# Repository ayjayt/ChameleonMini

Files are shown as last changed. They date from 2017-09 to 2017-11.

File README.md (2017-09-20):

Chameleon-Mini
==============
This is the official repository of ChameleonMini, a freely programmable, portable tool for NFC security analysis that can emulate and clone contactless cards, read RFID tags and sniff/log RF data. Thanks to over 1700 backers from our [Kickstarter project](https://www.kickstarter.com/projects/1980078555/chameleonmini-a-versatile-nfc-card-emulator-and-mo), the current Revision G has been realized by Kasper & Oswald GmbH.

The ChameleonMini RevG is now also available via the Kasper & Oswald [Webshop](https://shop.kasper.it/). Thank you for supporting the project!

First Steps
-----------
To upgrade the firmware of your ChameleonMini, please visit the [Getting Started page](http://rawgit.com/emsec/ChameleonMini/master/Doc/Doxygen/html/Page_GettingStarted.html) from the [doxygen documentation](http://rawgit.com/emsec/ChameleonMini/master/Doc/Doxygen/html/index.html).

Supported Cards and Codecs
--------------------------
See [here](https://github.com/emsec/ChameleonMini/wiki/Supported-Cards-and--Codecs).

Questions
---------
If you have any questions, please visit the [Issues page](https://github.com/emsec/ChameleonMini/issues) and ask your questions there so everyone benefits from the answer.

Repository Structure
--------------------
The code repository contains
* Doc: A doxygen documentation 
* Drivers: Chameleon drivers for Windows and Linux
* Dumps: Dumps of different smartcards
* Hardware: The layout and schematics of the PCB
* Firmware: The complete firmware including a modified Atmel DFU bootloader and LUFA
* Software: Contains a python tool for an easy configuration (and more) of the ChameleonMini, Note that this is currently under construction
* RevE: Contains the whole contents of the discontinued RevE repository.

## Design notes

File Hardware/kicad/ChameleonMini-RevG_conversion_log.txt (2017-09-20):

#********** START OF renumber-sheet.ulp ULP Version 4.4.4 08-08-2017 :04:16:28 LOG **********#
#OldRef				SheetNumber	NewRef
B+				1	B+53
B-				1	B-53
LBUTTON				1	LBUTTON53
LEDGREEN				1	LEDGREEN53
LEDRED				1	LEDRED53
RBTN				1	RBTN53
#********** END OF renumber-sheet.ulp ULP Version 4.4.4 08-08-2017 :04:16:28 LOG **********#

#********** START OF fix_via_hack.ulp ULP Version 4.7.0 08-08-2017 :04:16:36 LOG **********#
TRACK	WireCount=1		Net=+3V3				start(X=34925.000000 Y=49212.500000)	end(X=34925.000000 Y=51435.000000 )
TRACK	WireCount=2		Net=N$22				start(X=48463.200000 Y=59436.000000)	end(X=48463.200000 Y=59131.200000 )
TRACK	WireCount=3		Net=N$22				start(X=48463.200000 Y=59131.200000)	end(X=48158.400000 Y=59131.200000 )
TRACK	WireCount=4		Net=N$22				start(X=48158.400000 Y=59131.200000)	end(X=48158.400000 Y=59436.000000 )
TRACK	WireCount=5		Net=N$22				start(X=48158.400000 Y=59131.200000)	end(X=48158.400000 Y=58826.400000 )
TRACK	WireCount=6		Net=N$23				start(X=47853.600000 Y=59436.000000)	end(X=47548.800000 Y=59436.000000 )
TRACK	WireCount=7		Net=N$23				start(X=47548.800000 Y=59436.000000)	end(X=47548.800000 Y=59131.200000 )
TRACK	WireCount=8		Net=N$23				start(X=47548.800000 Y=59131.200000)	end(X=47853.600000 Y=59131.200000 )
TRACK	WireCount=9		Net=N$23				start(X=47853.600000 Y=59131.200000)	end(X=47853.600000 Y=58826.400000 )
TRACK	WireCount=10		Net=N$23				start(X=47853.600000 Y=58826.400000)	end(X=47548.800000 Y=58826.400000 )
VIA	ViaCount=1		Net=+3V3				(X=34925.000000 Y=49212.500000)	LayerStart=1	LayerEnd=16
VIA	ViaCount=2		Net=+3V3				(X=34925.000000 Y=51435.000000)	LayerStart=1	LayerEnd=16
VIA	ViaCount=3		Net=GND				(X=36512.400000 Y=63341.200000)	LayerStart=1	LayerEnd=16
VIA	ViaCount=4		Net=GND				(X=45720.000000 Y=24447.500000)	LayerStart=1	LayerEnd=16
PADFILL	PadCount=2		Net=GND				(X=42227.500000 Y=70485.000000)	LayerStart=16	LayerEnd=16
PADFILL	PadCount=5		Net=GND				(X=39052.500000 Y=36195.000000)	LayerStart=16	LayerEnd=16
PADFILL	PadCount=22		Net=+3V3				(X=47702.500000 Y=61912.500000)	LayerStart=1	LayerEnd=1
PADFILL	PadCount=24		Net=+3V3				(X=44132.600000 Y=36435.000000)	LayerStart=1	LayerEnd=1
PADFILL	PadCount=28		Net=+3V3				(X=33178.800000 Y=32942.500000)	LayerStart=1	LayerEnd=1
PADFILL	PadCount=30		Net=+3V3				(X=35320.000000 Y=59372.500000)	LayerStart=1	LayerEnd=1
PADFILL	PadCount=32		Net=+3V3				(X=40322.500000 Y=41987.500000)	LayerStart=1	LayerEnd=1
PADFILL	PadCount=34		Net=+3V3				(X=46277.500000 Y=63500.000000)	LayerStart=1	LayerEnd=1
PADFILL	PadCount=40		Net=+3V3				(X=46990.000000 Y=53897.500000)	LayerStart=1	LayerEnd=1
PADFILL	PadCount=42		Net=+3V3				(X=27700.000000 Y=53975.000000)	LayerStart=1	LayerEnd=1
PADFILL	PadCount=64		Net=+3V3				(X=40163.700000 Y=32942.500000)	LayerStart=1	LayerEnd=1
PADFILL	PadCount=68		Net=+3V3				(X=49212.400000 Y=39292.500000)	LayerStart=1	LayerEnd=1
PADFILL	PadCount=94		Net=+3V3				(X=40500.000000 Y=45952.500000)	LayerStart=1	LayerEnd=1
PADFILL	PadCount=104		Net=+3V3				(X=43900.000000 Y=53352.500000)	LayerStart=1	LayerEnd=1
PADFILL	PadCount=116		Net=+3V3				(X=35700.000000 Y=57552.500000)	LayerStart=1	LayerEnd=1
PADFILL	PadCount=124		Net=+3V3				(X=32300.000000 Y=51752.500000)	LayerStart=1	LayerEnd=1
PADFILL	PadCount=131		Net=+3V3				(X=47795.000000 Y=63502.500000)	LayerStart=1	LayerEnd=1
PADFILL	PadCount=137		Net=+3V3				(X=47005.000000 Y=35662.500000)	LayerStart=1	LayerEnd=1
PADFILL	PadCount=142		Net=+3V3				(X=46252.500000 Y=40337.500000)	LayerStart=1	LayerEnd=1
PADFILL	PadCount=145		Net=+3V3				(X=44072.500000 Y=58102.500000)	LayerStart=1	LayerEnd=1
PADFILL	PadCount=149		Net=+3V3				(X=49272.500000 Y=59372.500000)	LayerStart=1	LayerEnd=1
PADFILL	PadCount=150		Net=+3V3				(X=49272.500000 Y=60642.500000)	LayerStart=1	LayerEnd=1
PADFILL	PadCount=156		Net=+3V3				(X=42477.500000 Y=37110.000000)	LayerStart=1	LayerEnd=1
PADFILL	PadCount=157		Net=+3V3				(X=41977.500000 Y=37110.000000)	LayerStart=1	LayerEnd=1
PADFILL	PadCount=158		Net=+3V3				(X=41477.500000 Y=37110.000000)	LayerStart=1	LayerEnd=1
PADFILL	PadCount=163		Net=+3V3				(X=34940.000000 Y=35345.000000)	LayerStart=1	LayerEnd=1
PADFILL	PadCount=168		Net=+3V3				(X=38750.000000 Y=35345.000000)	LayerStart=1	LayerEnd=1
PADFILL	PadCount=214		Net=+3V3				(X=38900.000000 Y=33987.500000)	LayerStart=1	LayerEnd=1
PADFILL	PadCount=217		Net=+3V3				(X=34442.500000 Y=32687.500000)	LayerStart=1	LayerEnd=1
PADFILL	PadCount=226		Net=+3V3				(X=35457.500000 Y=60642.500000)	LayerStart=1	LayerEnd=1
PADFILL	PadCount=239		Net=+3V3				(X=40005.000000 Y=36297.500000)	LayerStart=1	LayerEnd=1
PADFILL	PadCount=246		Net=+3V3				(X=43395.000000 Y=31115.100000)	LayerStart=1	LayerEnd=1
PADFILL	PadCount=247		Net=+3V3				(X=46252.500000 Y=61912.500000)	LayerStart=1	LayerEnd=1
PADFILL	PadCount=256		Net=+3V3				(X=36195.000000 Y=36297.500000)	LayerStart=1	LayerEnd=1
PADFILL	PadCount=272		Net=+3V3				(X=48792.500000 Y=55403.700000)	LayerStart=1	LayerEnd=1
PADFILL	PadCount=298		Net=+3V3				(X=28035.000000 Y=52070.000000)	LayerStart=1	LayerEnd=1
#********** END OF fix_via_hack.ulp ULP Version 4.7.0 08-08-2017 :04:16:36 LOG **********#

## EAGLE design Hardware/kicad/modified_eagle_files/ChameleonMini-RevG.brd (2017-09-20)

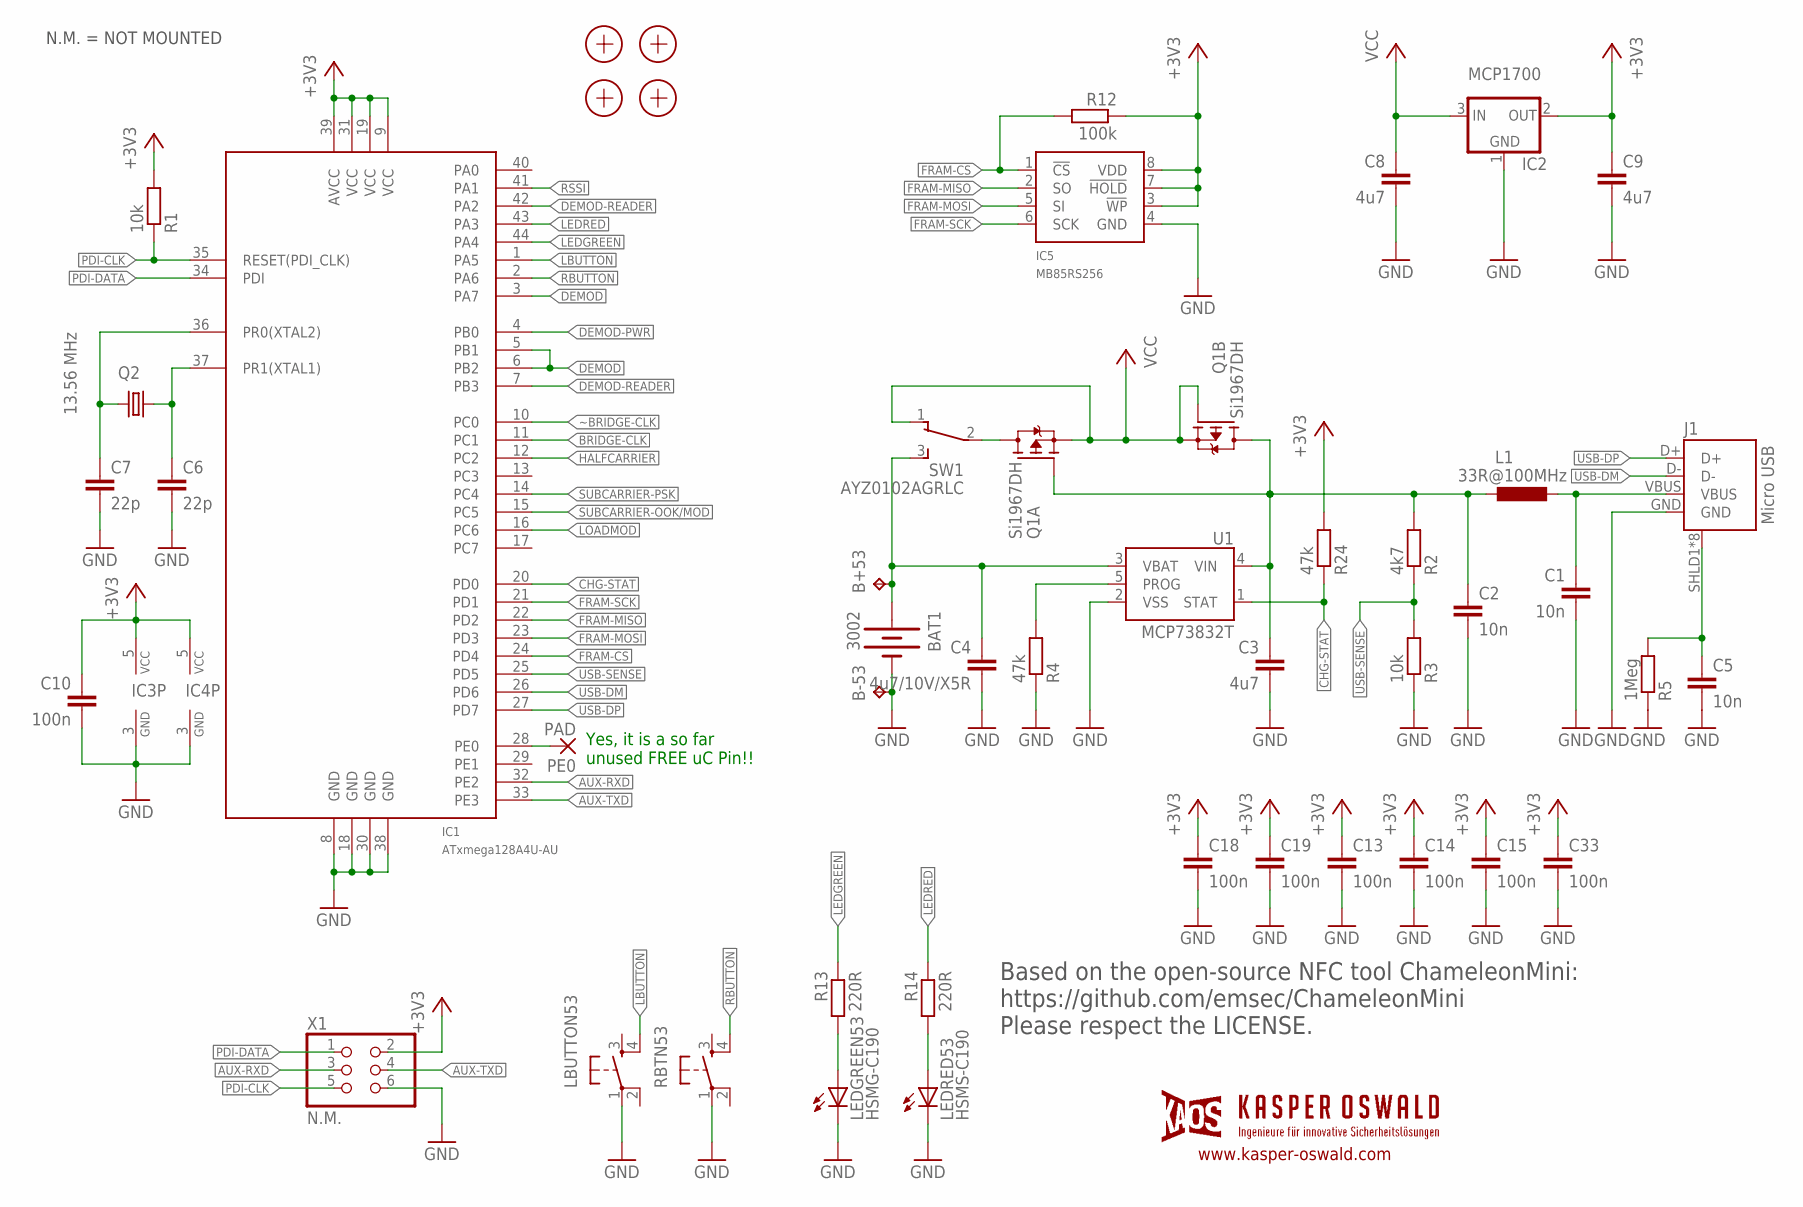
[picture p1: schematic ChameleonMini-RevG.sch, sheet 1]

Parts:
B+53: TPTP18SQ; TP18SQ
B-53: TPTP18SQ; TP18SQ
BAT1: 3002; BATTCON_20MM
C1, C2: 10n; C1206K
C3, C8, C9: 4u7; C0603K
C4: 4u7/10V/X5R; C0603K
C5: 10n; C0603K
C6, C7: 22p; C0603K
C10, C13, C14, C15, C18, C19, C33: 100n; C0603K
IC1: ATxmega128A4U-AU; TQFP44
IC2: MCP1700; SOT23
IC3: 7408; SC70-5
IC4: 7486; SC70-5
IC5: MB85RS256; SO-08
J1: Micro USB; USB-MICROB-10118194
L1: 33R@100MHz; L2012C
LBUTTON53: SWITCH_SPST_4_PINSQUARE; TACTILE-SWITCH-SMD
LEDGREEN53: HSMG-C190; CHIPLED-0603
LEDRED53: HSMS-C190; CHIPLED-0603
PE0: PAD; SMD1,27-2,54
Q1: Si1967DH; SOT363
Q2: 13.56 MHz; 5MMX3.2MM
R1, R3: 10k; R0603
R2: 4k7; R0603
R4, R24: 47k; R0603
R5: 1Meg; R0603
R12: 100k; R0603
R13, R14: 220R; R0603
RBTN53: SWITCH_SPST_4_PINSQUARE; TACTILE-SWITCH-SMD
SW1: AYZ0102AGRLC
U1: MCP73832T; SOT23-5
X1: N.M.; PINHD-2X3-2.54-EDGE
X2, X4, X5, X6: PASSER-07; PASSER_07MM

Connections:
+3V3: C9.1, C10.1, C13.1, C14.1, C15.1, C18.1, C19.1, C33.1, IC1.9 (VCC), IC1.19 (VCC), IC1.31 (VCC), IC1.39 (AVCC), IC2.2 (OUT), IC3.5 (VCC), IC4.5 (VCC), IC5.3 (!WP), IC5.7 (!HOLD), IC5.8 (VDD), R1.2, R12.1, R24.2, X1.2; also elsewhere on the board
AUX-RXD: IC1.32 (PE2), X1.3
AUX-TXD: IC1.33 (PE3), X1.4
BRIDGE-CLK: IC1.11 (PC1); also elsewhere on the board
CHG-STAT: IC1.20 (PD0), R24.1, U1.1 (STAT)
DEMOD: IC1.3 (PA7), IC1.5 (PB1), IC1.6 (PB2); also elsewhere on the board
DEMOD-PWR: IC1.4 (PB0); also elsewhere on the board
DEMOD-READER: IC1.7 (PB3), IC1.42 (PA2); also elsewhere on the board
FRAM-CS: IC1.24 (PD4), IC5.1 (!CS), R12.2
FRAM-MISO: IC1.22 (PD2), IC5.2 (SO)
FRAM-MOSI: IC1.23 (PD3), IC5.5 (SI)
FRAM-SCK: IC1.21 (PD1), IC5.6 (SCK)
GND: B-53.TP, BAT1.-, C1.2, C2.2, C3.2, C4.2, C5.2, C6.2, C7.2, C8.2, C9.2, C10.2, C13.2, C14.2, C15.2, C18.2, C19.2, C33.2, IC1.8 (GND), IC1.18 (GND), IC1.30 (GND), IC1.38 (GND), IC2.1 (GND), IC3.3 (GND), IC4.3 (GND), IC5.4 (GND), J1.GND, LBUTTON53.1, LEDGREEN53.C, LEDRED53.C, R3.1, R4.1, R5.1, RBTN53.1, U1.2 (VSS), X1.6; also elsewhere on the board
HALFCARRIER: IC1.12 (PC2); also elsewhere on the board
LBUTTON: IC1.1 (PA5), LBUTTON53.4
LEDGREEN: IC1.44 (PA4), R13.1
LEDRED: IC1.43 (PA3), R14.1
LOADMOD: IC1.16 (PC6); also elsewhere on the board
unnamed: C7.1, IC1.36 (PR0(XTAL2)), Q2.3 (2)
unnamed: C1.1, J1.VBUS, L1.1
unnamed: C6.1, IC1.37 (PR1(XTAL1)), Q2.1
unnamed: LEDGREEN53.A, R13.2
unnamed: LEDRED53.A, R14.2
unnamed: Q1.6 (D), SW1.2
unnamed: C2.1, C3.1, L1.2, Q1.2 (G), Q1.3 (D), R2.2, U1.4 (VIN)
unnamed: IC1.28 (PE0), PE0.1
unnamed: R4.2, U1.5 (PROG)
unnamed: B+53.TP, BAT1.+2 (+), C4.1, SW1.3 (S), U1.3 (VBAT)
unnamed: C5.1, J1.SHLD1 (SHIELD), J1.SHLD2 (SHIELD), J1.SHLD3 (SHIELD), J1.SHLD4 (SHIELD), J1.SHLD5 (SHIELD), J1.SHLD6 (SHIELD), J1.SHLD7 (SHIELD), J1.SHLD8 (SHIELD), R5.2
PDI-CLK: IC1.35 (RESET(PDI_CLK)), R1.1, X1.5
PDI-DATA: IC1.34 (PDI), X1.1
RBUTTON: IC1.2 (PA6), RBTN53.4
RSSI: IC1.41 (PA1); also elsewhere on the board
SUBCARRIER-OOK/MOD: IC1.15 (PC5); also elsewhere on the board
SUBCARRIER-PSK: IC1.14 (PC4); also elsewhere on the board
USB-DM: IC1.26 (PD6), J1.D-
USB-DP: IC1.27 (PD7), J1.D+
USB-SENSE: IC1.25 (PD5), R2.1, R3.2
VCC: C8.1, IC2.3 (IN), Q1.1 (S), Q1.4 (S), Q1.5 (G), SW1.1 (O)
~BRIDGE-CLK: IC1.10 (PC0); also elsewhere on the board

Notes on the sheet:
Based on the open-source NFC tool ChameleonMini: https://github.com/emsec/ChameleonMini Please respect the LICENSE.
N.M. = NOT MOUNTED
Yes, it is a so far unused FREE uC Pin!!
www.kasper-oswald.com

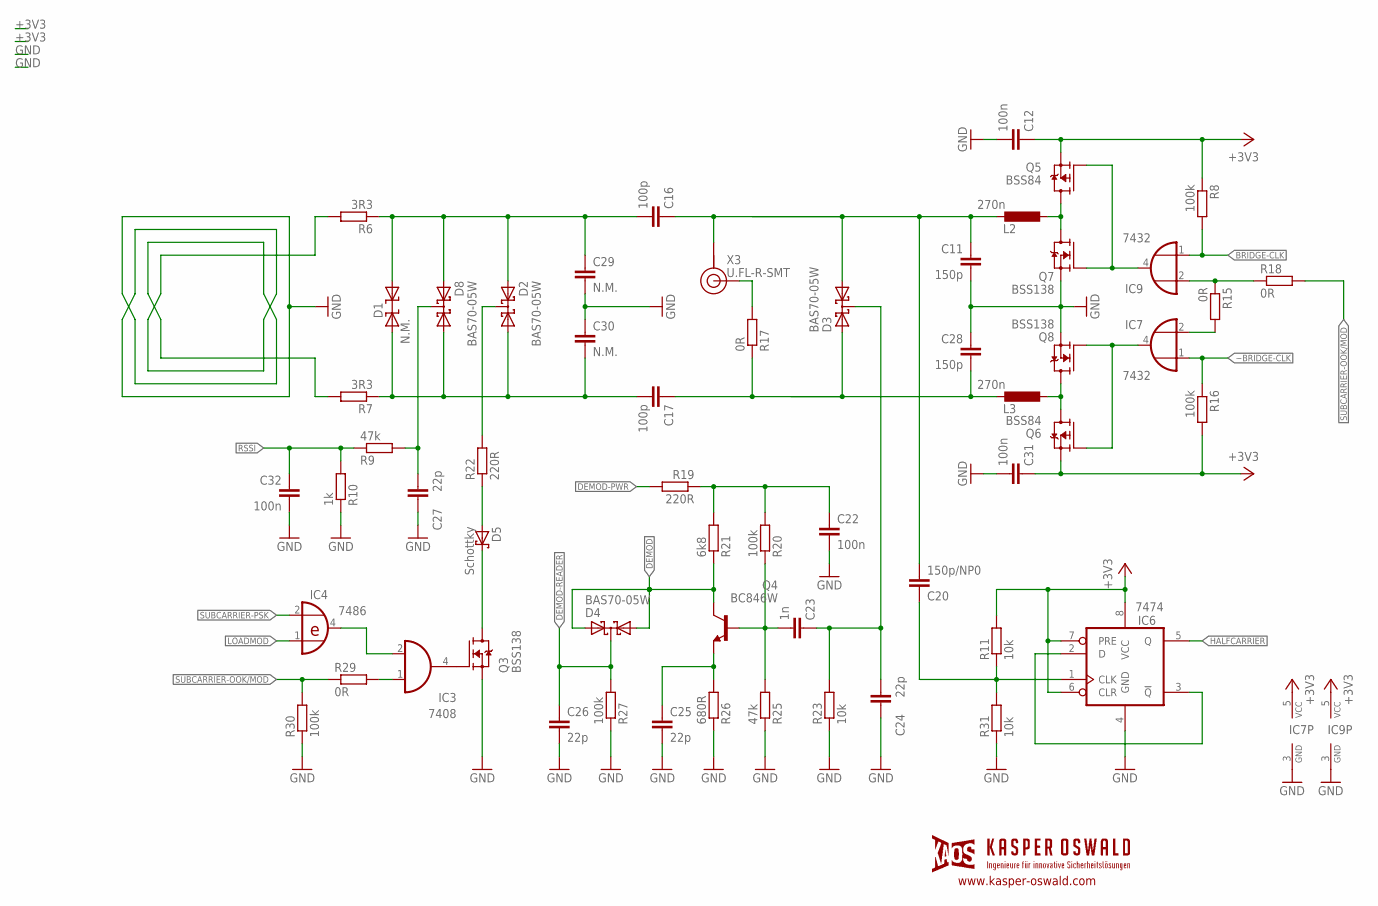
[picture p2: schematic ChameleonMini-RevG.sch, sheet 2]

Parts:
C11, C28: 150p; C0603K
C12, C22, C31, C32: 100n; C0603K
C16, C17: 100p; C0603K
C20: 150p/NP0; C0603K
C23: 1n; C0603K
C24, C25, C26, C27: 22p; C0603K
C29, C30: N.M.; C0603K
D1: N.M.; DO214AC
D2, D3, D4, D8: BAS70-05W; SOT323
D5: Schottky; SOD323(F)
IC3: 7408; SC70-5
IC4: 7486; SC70-5
IC6: 7474; VSSOP8
IC7, IC9: 7432; SC70-5
L2, L3: 270n; L2012C
Q3, Q7, Q8: BSS138; SOT323
Q4: BC846W; SOT323
Q5, Q6: BSS84; SOT323
R6, R7: 3R3; R0603
R8, R16, R20, R27, R30: 100k; R0603
R9, R25: 47k; R0603
R10: 1k; R0603
R11, R23, R31: 10k; R0603
R15, R17, R18, R29: 0R; R0603
R19, R22: 220R; R0603
R21: 6k8; R0603
R26: 680R; R0603
X3: U.FL-R-SMT

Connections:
+3V3: C12.1, C31.1, IC6.6 (CLR), IC6.7 (PRE), IC6.8 (VCC), IC7.5 (VCC), IC9.5 (VCC), Q5.2 (S), Q6.2 (S), R8.1, R11.2, R16.2; also elsewhere on the board
ANTENNA-A: C11.1, C16.1, C20.2, D3.2 (A2), L2.2, X3.GND1 (GND)
ANTENNA-B: C17.1, C28.2, D3.1 (A1), L3.2, R17.1
BRIDGE-1: IC9.4 (O), Q5.1 (G), Q7.1 (G)
BRIDGE-2: IC7.4 (O), Q6.1 (G), Q8.1 (G)
BRIDGE-CLK: IC9.1 (I0), R8.2; also elsewhere on the board
DEMOD: D4.1 (A1), D4.2 (A2), Q4.3 (C), R21.1; also elsewhere on the board
DEMOD-PWR: R19.2; also elsewhere on the board
DEMOD-READER: C26.1, D4.3 (K), R27.2; also elsewhere on the board
GND: C11.2, C12.2, C22.2, C24.2, C25.2, C26.2, C27.2, C28.1, C29.2, C30.1, C31.2, C32.2, IC6.4 (GND), IC7.3 (GND), IC9.3 (GND), Q3.2 (S), Q7.2 (S), Q8.2 (S), R6.2, R7.2, R10.1, R23.1, R25.1, R26.1, R27.1, R30.1, R31.1; also elsewhere on the board
HALFCARRIER: IC6.5 (Q); also elsewhere on the board
LOADMOD: IC4.1 (I0); also elsewhere on the board
MOD-DEMOD: D2.3 (K), R22.2
MOD-DEMOD1: C23.1, C24.1, D3.3 (K), R23.2
unnamed: C25.1, Q4.2 (E), R26.2
unnamed: IC7.2 (I1), R15.2
unnamed: D5.1 (K), Q3.3 (D)
unnamed: IC6.2 (D), IC6.3 (!Q)
unnamed: C16.2, C29.1, D1.2, D2.1 (A1), D8.1 (A1), R6.1
unnamed: L2.1, Q5.3 (D), Q7.3 (D)
unnamed: IC3.2 (I1), IC4.4 (O)
unnamed: D5.2 (A), R22.1
unnamed: IC3.4 (O), Q3.1 (G)
unnamed: R17.2, X3.SIG
unnamed: L3.1, Q6.3 (D), Q8.3 (D)
unnamed: C17.2, C30.2, D1.1, D2.2 (A2), D8.2 (A2), R7.1
unnamed: C27.1, D8.3 (K), R9.2
unnamed: IC9.2 (I1), R15.1, R18.1
unnamed: C23.2, Q4.1 (B), R20.1, R25.2
unnamed: C20.1, IC6.1 (CLK), R11.1, R31.2
unnamed: IC3.1 (I0), R29.2
unnamed: C22.1, R19.1, R20.2, R21.2
RSSI: C32.1, R9.1, R10.2; also elsewhere on the board
SUBCARRIER-OOK/MOD: R18.2, R29.1, R30.2; also elsewhere on the board
SUBCARRIER-PSK: IC4.2 (I1); also elsewhere on the board
~BRIDGE-CLK: IC7.1 (I0), R16.1; also elsewhere on the board

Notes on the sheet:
www.kasper-oswald.com

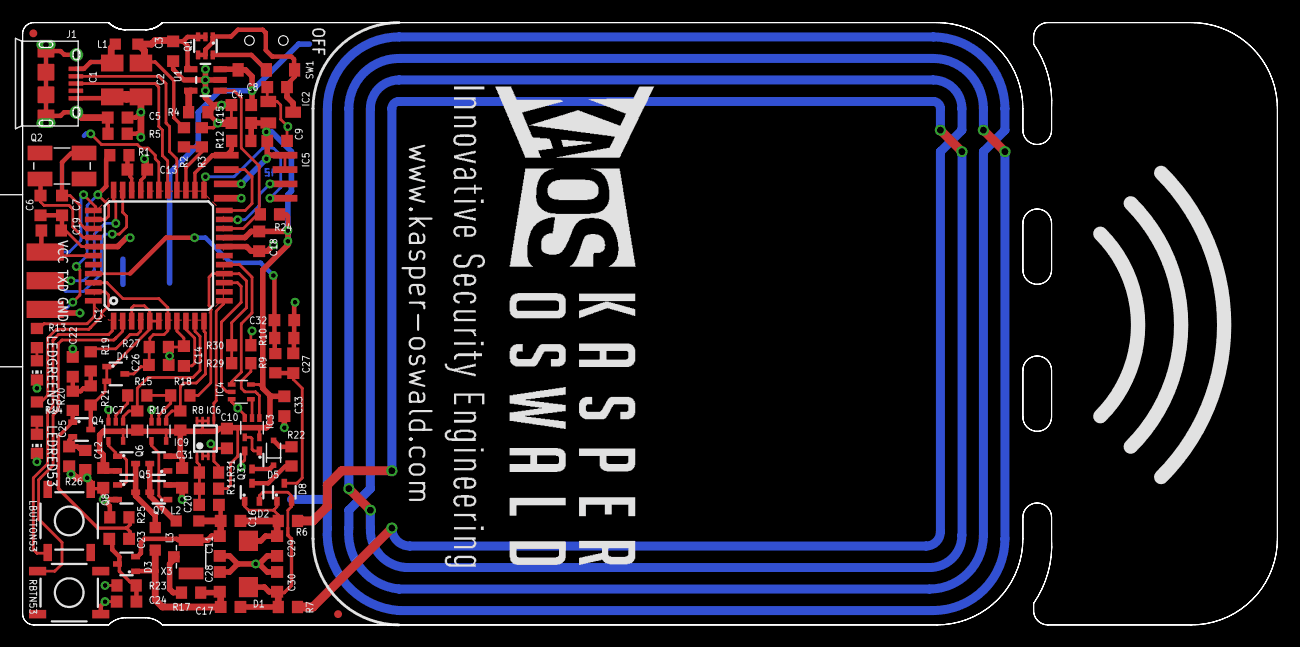
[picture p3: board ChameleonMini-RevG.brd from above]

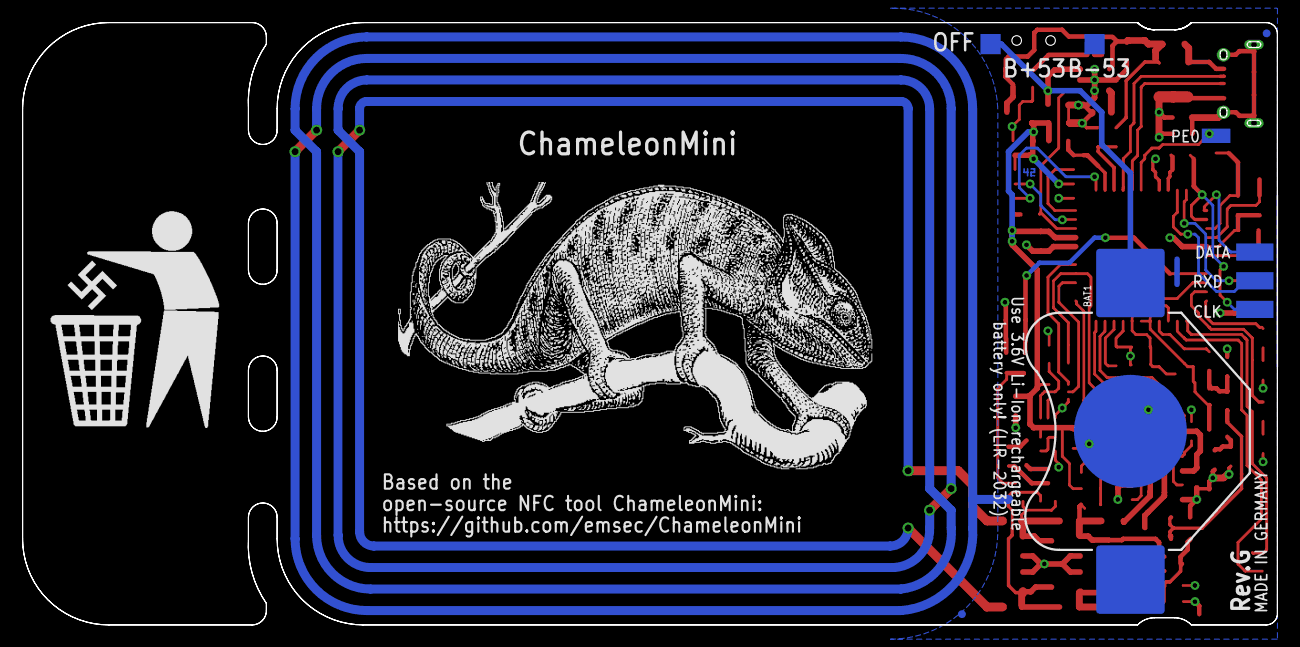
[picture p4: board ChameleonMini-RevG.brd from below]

Board: 2 copper layers, 111.1 x 53.3 mm, 104 parts (6 on the bottom side), 64 nets.

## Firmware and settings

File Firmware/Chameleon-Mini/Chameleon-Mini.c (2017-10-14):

#include "Chameleon-Mini.h"
#include <avr/sleep.h>
#include <avr/io.h>
#include <avr/power.h>

void enableUSARTD1(void){
		PORTD.OUT |= PIN7_bm;
		PORTD.DIRSET = PIN7_bm;
		PORTD.DIRCLR = PIN6_bm;
		USARTD1.CTRLC = (uint8_t) USART_CHSIZE_8BIT_gc | (0b11<<4);
    USARTD1.BAUDCTRLA = (uint8_t) (3270);
    USARTD1.BAUDCTRLB = ( 0b1001 << USART_BSCALE0_bp ) | ( 3270>>8 );
		
	  USARTD1.CTRLB |= USART_RXEN_bm;
		USARTD1.CTRLB |= USART_TXEN_bm;
}


int main(void)
{
	SystemInit(); // watchdog and oscillator stuff
	SettingsLoad(); // loads stuff from ee
	LEDInit(); // Sets direction Register
	MemoryInit(); //FRAM DMA stuff 
	CodecInitCommon(); // Does Pins for Modems
	ConfigurationInit(); // loads new configuration and finishes CodecInit
	enableUSARTD1();
	TerminalInit(); // sets port direction pon pind5 // senses usb, might be why clock turns back on
	RandomInit(); // empty function (literally 0 lines)
	ButtonInit(); // just some pullups and stuff
	AntennaLevelInit(); // sets ome things
	LogInit();
	SystemInterruptInit(); // Just enable all interrupts

	CLK.USBCTRL &= ~(1);
	USB.CTRLA &= ~(1<<7);
	SystemStopUSBClock();
	
	

	while(1) {
		
		if (SystemTick100ms()) {
			RandomTick(); // "entropy generator"
			TerminalTick(); // PRETTY INVOLVED, ./Termina/* needs going through
			ButtonTick(); //Any results are stored in the settings structure (including button action function)
			LogTick(); //
			LEDTick(); //

			ApplicationTick(); // believe this is mifare related, CHECK
			CommandLineTick();  // happens in TerminalTick too, doesn't look like it does much
			AntennaLevelTick(); //
		}
		TerminalTask();
		LogTask();
		ApplicationTask();
		CodecTask();
		newUART();
	}
}

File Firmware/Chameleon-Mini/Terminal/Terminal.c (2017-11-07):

#include "Terminal.h"
#include "../System.h"
#include "../LEDHook.h"

// ptc is a layer to handle uart output
void ptc(char c){
	do{
			/* Wait until it is possible to put data into TX data register.*/
	} while(!( (USARTD1.STATUS & USART_DREIF_bm) != 0));
	USARTD1.DATA = c;
}
// pts is a loop of pts
void pts(const char * str, uint16_t len){
	uint8_t i = 0;
	if (len){
		for(; i < len; i++){
			ptc(str[i]);
		}
	} else {
		while (str[i] != 0){
			ptc(str[i++]);
		} ptc(0);
	}
}
// ftc is a layer to handle uart input
volatile int16_t gtc(){
	volatile int16_t recv;
	if (USARTD1.STATUS & USART_RXCIF_bm) {
		recv = USARTD1.DATA;
		//ptc((char)recv); // get rid of this get rid of this get rid of this
		return (int16_t) recv;
	} else {
		return -1;
	}
}

#define INIT_DELAY		(2000 / SYSTEM_TICK_MS)


uint8_t TerminalBuffer[TERMINAL_BUFFER_SIZE];
TerminalStateEnum TerminalState = TERMINAL_UNINITIALIZED;

// TerminalSendString was part of Terminmal.c for USB so I left it
void TerminalSendString(const char* s) {
	pts(s, 0);
}
// TerminalSendStringp is a '\=' send string
void TerminalSendStringP(const char* s) {
    char c;

    while( (c = pgm_read_byte(s++)) != '\0' ) {
        TerminalSendChar(c);
    }
}

/*
void TerminalSendHex(void* Buffer, uint16_t ByteCount)
{
    char* pTerminalBuffer = (char*) TerminalBuffer;

    BufferToHexString(pTerminalBuffer, sizeof(TerminalBuffer), Buffer, ByteCount);

    TerminalSendString(pTerminalBuffer);
}

*/

// A circular buffer
char bigBuffer[142];
uint16_t writeC = 0, readC = 0, mark = 0;
// returns values from bigBuffer if a \r was found
int16_t getByteFromBuffer(void){
	if (readC == 142){
		readC = 0;
	}
	if (mark){
		if ((bigBuffer[readC] == '\r')||(bigBuffer[readC] == 0x01)||(bigBuffer[readC] == 0x04)) {
			mark--;
		}
		return bigBuffer[readC++];
	}
	return -1;
}
// writes to the circular buffer
void newUART(void){
	volatile int16_t rcvLocal = gtc();
	if (rcvLocal != -1){
		bigBuffer[writeC++] = (char)rcvLocal;
		if (writeC == 142) {
			writeC = 0;
		}
		if (((char)rcvLocal == '\r') || ((char)rcvLocal == 0x01) || ((char)rcvLocal == 0x04)) {
			mark++;
		}
	}
}

void TerminalSendBlock(const void* Buffer, uint16_t ByteCount)
{
  	pts(Buffer, ByteCount); 
}


static void ProcessByte(void) {
		int16_t Byte = getByteFromBuffer();

    if (Byte >= 0) {
        /* Byte received */
    	LEDHook(LED_TERMINAL_RXTX, LED_PULSE);

        if (XModemProcessByte(Byte)) { // check xmodem
            /* XModem handled the byte */
        } else if (CommandLineProcessByte(Byte)) {
            /* CommandLine handled the byte */
        }
    }
}

static void SenseVBus(void)
{
		TerminalState = TERMINAL_INITIALIZED;
}

void TerminalInit(void)
{
   // Could put UART Init here 
}

void TerminalTask(void)
{
	if (TerminalState == TERMINAL_INITIALIZED) {

		// maybe these were used to actually send out what was in a buffer?

		ProcessByte();
	}
}

void TerminalTick(void)
{
	SenseVBus();

	if (TerminalState == TERMINAL_INITIALIZED) {
		XModemTick();
		CommandLineTick();
	}
}

/** Event handler for the library USB Connection event. */
void EVENT_USB_Device_Connect(void)
{
	LEDHook(LED_TERMINAL_CONN, LED_ON);
}

/** Event handler for the library USB Disconnection event. */
void EVENT_USB_Device_Disconnect(void)
{
	LEDHook(LED_TERMINAL_CONN, LED_OFF);
}


/** Event handler for the library USB Configuration Changed event. */
void EVENT_USB_Device_ConfigurationChanged(void)
{
;
}

/** Event handler for the library USB Control Request reception event. */
void EVENT_USB_Device_ControlRequest(void)
{
;
}

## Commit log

2017-09-20 Added two non-firmware things:
    A folder generated during conversion to kicad- nothing useful
    Fixed a 1k to be the proper size
    [ChameleonMini-RevG.brd, ChameleonMini-RevG.sch]
2017-09-21 UART WORKS! Added some functions Some notes too, (how to turn off USB)
2017-10-06 tons of uart working
2017-10-14 UART now works as a library to trade commands- no XMODEM yet
2017-11-07 Modified so UART works with XMODEM
    XMODEM doesn't use \r to indicate commands, so I added 0x01 and 0x04 to mark that buffer should
    be processed
    [Terminal.c]

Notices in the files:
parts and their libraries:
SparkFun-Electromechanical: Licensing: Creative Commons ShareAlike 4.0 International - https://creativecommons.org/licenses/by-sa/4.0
